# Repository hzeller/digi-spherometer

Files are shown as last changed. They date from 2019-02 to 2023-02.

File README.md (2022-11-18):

A Digital Spherometer
=====================

Converting the sagittal measurement (SAG) from a dial indicator and converting
in your head to a sphere radius is a pain.

This project uses a microcontroller to make this more pleasent: it reads out
the digital indicator and converts the reading to a sphere radius value
printed on an OLED display. It also adds some other nifty features, such as
converting this into the ƒ/N for your mirror size. See [firmware]-page for
feature details.

The microcontroller is an [ATTiny85], the display is a 0.96" [SSD1306], or
1.3" [SH1106] compatible 128x64 OLED display with I²C interface.

Supported dial indicators are [Mitutoyo 543] (good, industry-standard quality)
and a generic [autoutlet-indicator] (relatively cheap, has 1μm resolution but
no documented accuracy figures. Sells under many different names).

The [case](./frame) to hold the dial indicator, microcontroller+display and
batteries is 3D-printed, the base can be laser-cut or machined from some metal
plate.

### Quicklinks

Case | Electronics | Firmware | Calibration
-----|-------------|----------|-------------
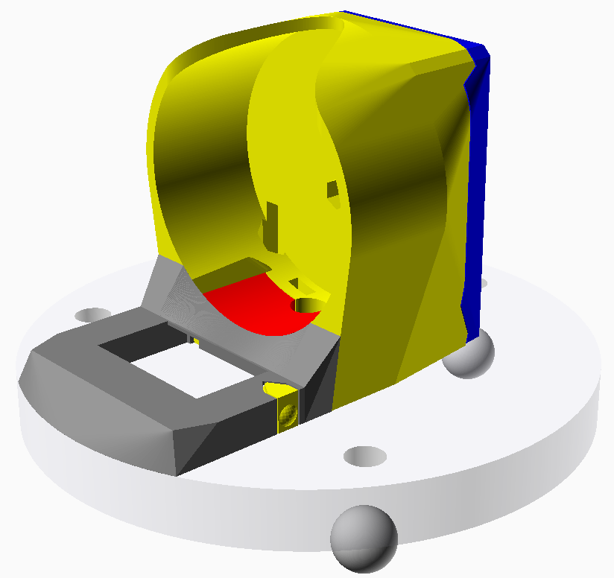
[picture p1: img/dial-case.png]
Case
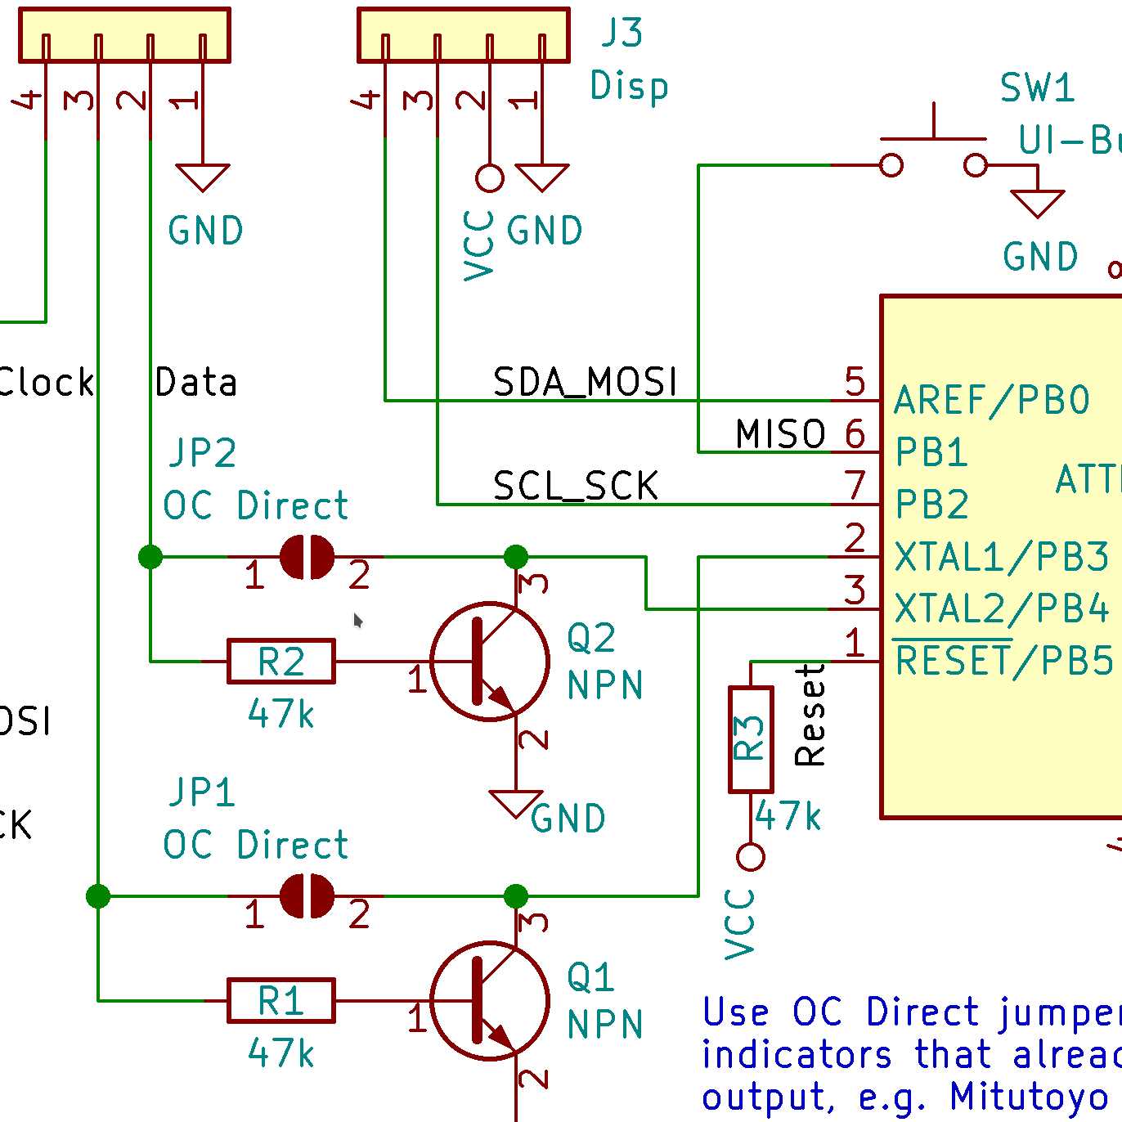
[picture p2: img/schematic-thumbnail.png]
Electronics
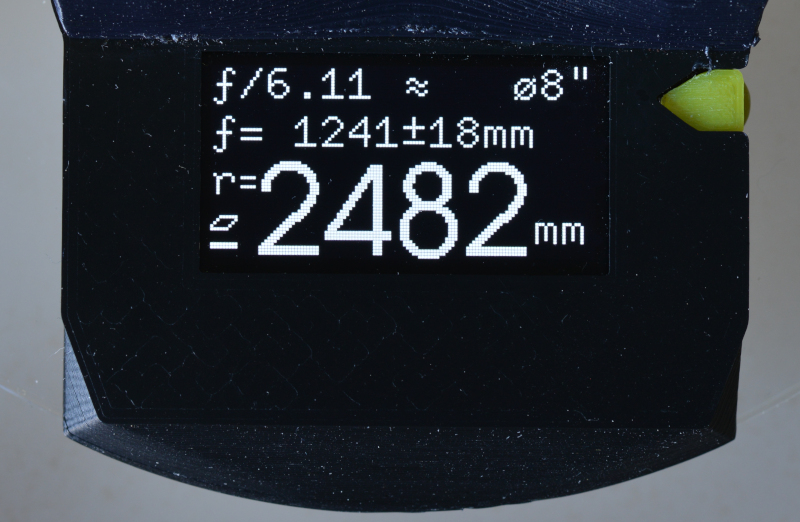
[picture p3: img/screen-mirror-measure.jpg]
Firmware
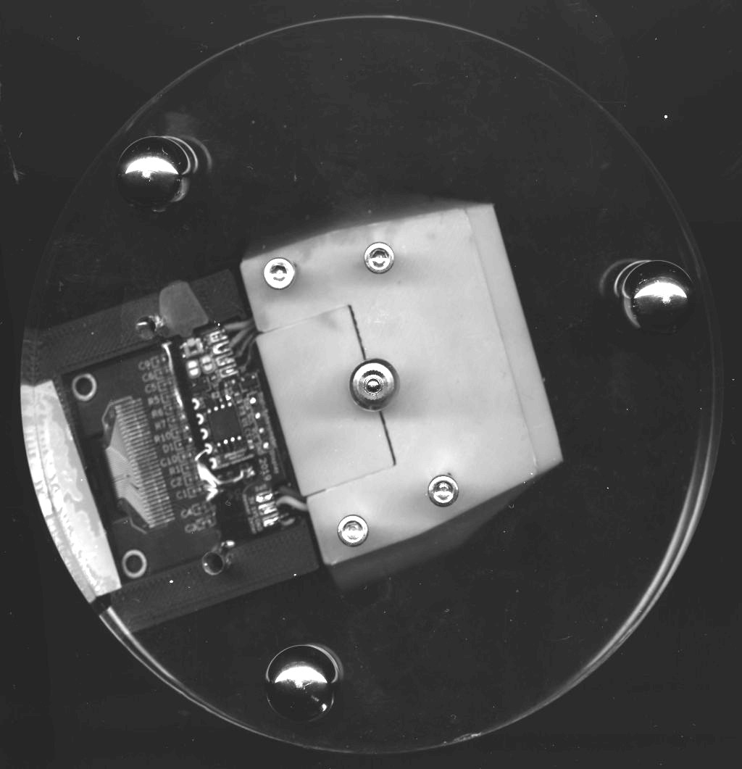
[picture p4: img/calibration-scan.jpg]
Calibration
 |  |  | 

### User Manual

Like any Spherometer, we first need to zero the device on a reference surface.
Typically this is done on a flat surface plate, so this spherometer allows for
that: place it on a flat surface and set the dial indicator to zero.

Unlike other spherometers, this device also allows for another (experimental)
mode: using the grinding tool as a reference surface. The convex shaped tool
has the same (but inverted) curvature as the mirror, so this can be used
as a reference, if the tool and mirror are already sufficiently mated. The
spherometer then can do the math to derive the value from that.

To use that mode, place the spherometer on the tool (make sure the balls and
indicator rest on the tiles not hitting a seam), and zero the dial indicator.
The arrow-shaped button the right side of the display allows to toggle between
the reference mode. The selected mode is highlighted.

Reference on Surface Plate         | Reference on Tool               |
-----------------------------------|---------------------------------|
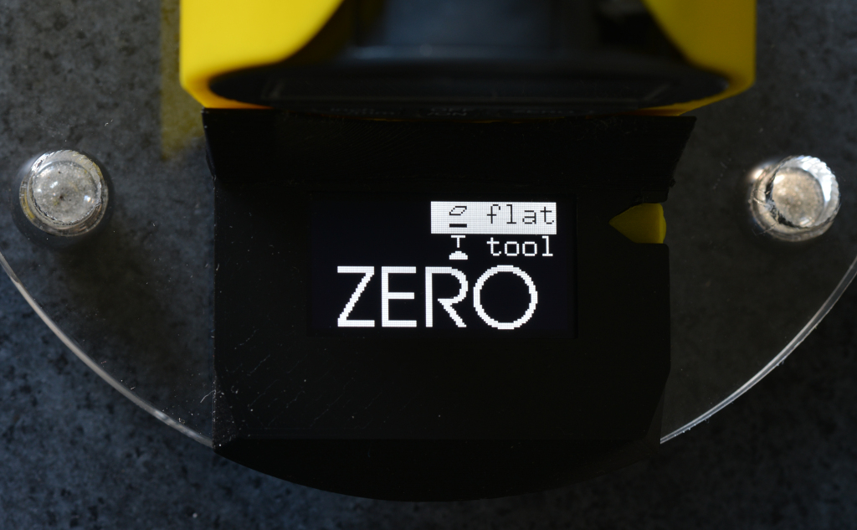
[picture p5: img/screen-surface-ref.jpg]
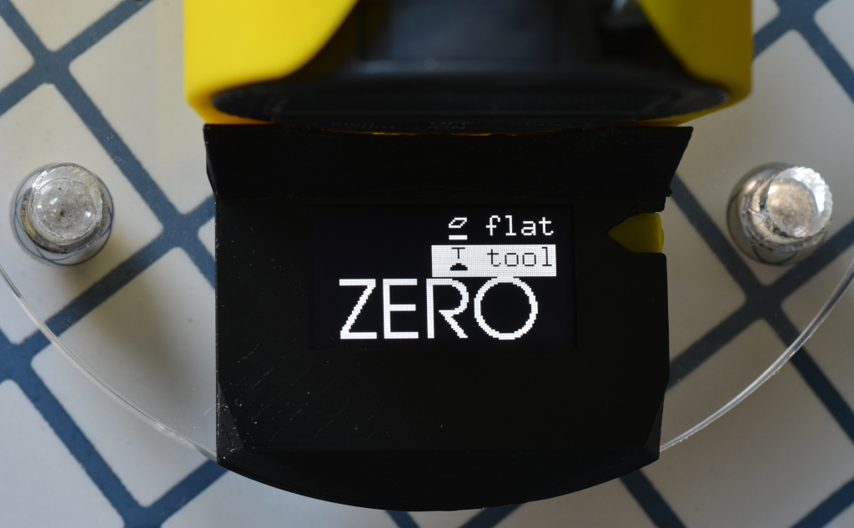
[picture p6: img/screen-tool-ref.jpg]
  | 

The tool reference is probably a bit less accurate, but it does not require
you to be in posession of a flat surface plate.

After the device is zeroed, place it on the mirror. It now shows all relevant
values on one screen. This is what you see from top to bottom:

 * The ƒ/N value for a given mirror size. The mirror size (chosen here: `⌀8"`)
   can be cycled through from a list with the arrow-button.
 * The focal length including error margins derived from dial-indicator error
   and spherometer leg-radius error.
 * The radius is shown in a large font

On the bottom left you see a symbol indicating which reference surface this
was against. There are two symbols indicating flat surface and tool referenced
(same symbols as used in the zero screen).

Millimeter | Inch |
-----------|------|
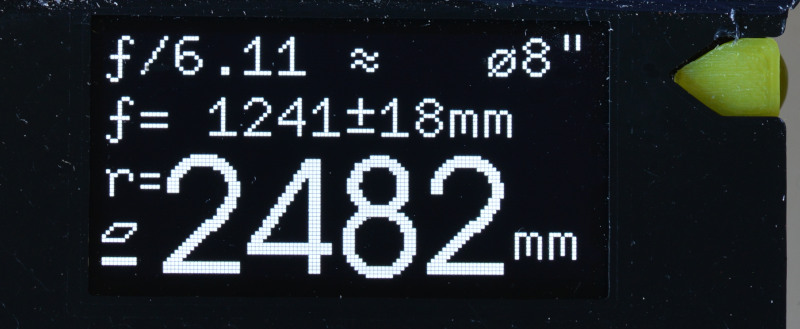
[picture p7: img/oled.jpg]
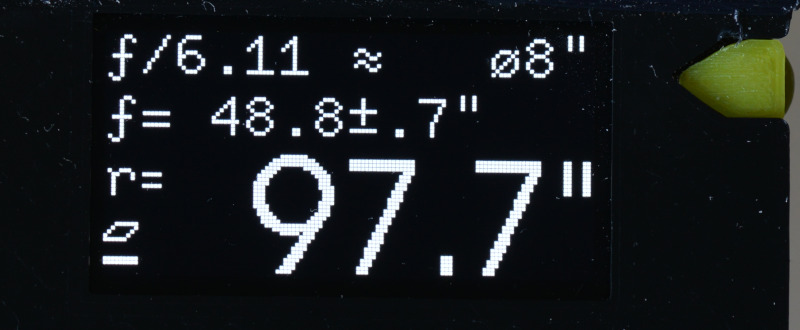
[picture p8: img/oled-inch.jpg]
 | 

So in this example we see in one screen, that this is a mirror with a radius
of about 2482mm, a focal length of 1241mm which is ƒ/6.11 for this
8" mirror. The reference surface was a flat surface plate.

Switching between metric and inch on the dial indicator automatically
switches the calculated values to the corresponding units.

The device does not need an additional power button: it auto-detects
when the drop-indicator is switched off and goes to sleep.

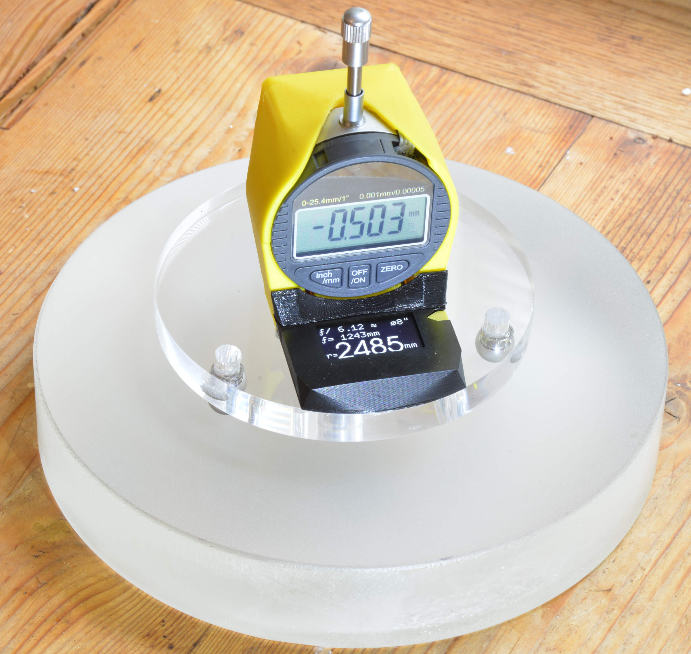
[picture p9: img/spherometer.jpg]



[attiny85]: https://www.microchip.com/wwwproducts/en/ATtiny85
[ssd1306]: https://www.ebay.com/sch/i.html?_nkw=ssd1306+i2c+128x64
[sh1106]: https://www.ebay.com/sch/i.html?_nkw=sh1106+i2c+128x64
[Mitutoyo 543]: https://www.mitutoyo.com/products/small-tool-instruments-and-data-management/indicators/digimatic-indicators/absolute-digimatic-indicator-id-s/
[autoutlet-indicator]: https://www.amazon.com/gp/product/B07C63VFN3
[avr-gcc]: https://gcc.gnu.org/wiki/avr-gcc
[firmware]: ./firmware/README.md

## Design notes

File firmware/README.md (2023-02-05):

Firmware Digi-Spherometer
=========================

The Firmware runs on an [ATTiny85]. The digital drop meter is connected to two
IO-pins, the [SSD1306 screen]/[SH1106 screen] is controlled via I²C.

See the [electronic](../pcb) section about the wiring.

### Install
To build, install the `avr-gcc` toolchain and `avrdude`. There is no
boot-loader, we directly program the chip with an AVR-compatible programmer
through the SPI in-circuit programming pins of the ATTiny85.

The first time the chip is programmed, make sure to set the fuses:
```bash
make fuse
```

Then, compiling and pushing new code to the ATTiny is as simple as invoking
`make flash`. There are some defines that you can pass directly on the
command-line, see [Makefile](./Makefile). In particular after
[calibration](../calibration), you might want to define the exact measured
spherometer radius.

```bash
make USER_DEFINES="-DSPHEROMETER_RADIUS_MM=50.2 -DALLOW_CONVEX_MEASUREMENTS=1" flash
```

The default compile works with the Autoutlet dial indicator. If you use a
Mitutoyo indicator, add `-DINDICATOR_MITUTOYO` to your `USER_DEFINES`.

These are the configuration options, settable via defines in the make commandline:

define                   | default value | Description
------------------------ |---------------|------------------------------------
DISP_SSD1306             | undefined     | Define if SSD1306 instead of SH1106 display is used
DISPLAY_I2C              | 0x78          | I²C address of display.
INDICATOR_DECIMALS       | 3             | Millimeter decimals supported. 3 means: resolution 1μm
INDICATOR_MITUTOYO       | undefined     | Read Mitutoyo instead of Autolet indicator
SPHEROMETER_RADIUS_MM    | 50.000        | Radius of spherometer ring, distance of balls to center.
SPHEROMETER_RADIUS_ERROR_MM | 0.1        | Accuracy of the spherometer radius. Influences error calculation
SPHEROMETER_FEET_BALL_DIAMETER_MM | 12.7 | Diameter of 'feet'-balls used for the ball correction.
TOOL_REFERENCE_FEATURE | undefined | If set to 1: Provide tool reference feature.
ALLOW_CONVEX_MEASUREMENTS| undefined     | If set to 1: Allow to measure also convex surfaces (shows radius negative and applies appropriate ball correction).
SCREENSAVER_SAMPLE_COUNT | undefined     | A number. If defined, turn off display after this number of samples with no change in measurement (good value would be around 1000). Use this for indicators such as Mitotoyo that don't auto-power off somewhat quickly. Reduces current consumption from ~15mA to ~4mA.

#### Mirror size choices for ƒ/N calculation
If you want to change the list of apertures to choose from for the
ƒ/N calculation (currently 6", 8", 10", 12" and 16") look for `aperture_items`
in `main.cc`.

### Interesting nitbits

#### Display and Font Handling
The ATTiny85 RAM is small (512 Byte), which does not allow for having a
frame-buffer for the 128x64 display (1KiB) in memory as many implementations do.
The fonts are compiled-in and directly copied from `PROGMEM`-memory.

The I²C and OLED display code is freshly implemented with only the relevant
features. The display-code only uses features from the SH1106 controller, so it
is compatible with SH1106 and SSD1306 (you still need a compile-time option
to distinguish the displays as there is a different pixel-offset).

The fonts were [generated as compact C-Arrays][bdfont.data] from bitmap BDF
fonts so that they can be compiled into the binary.

Fonts can be 'sparse' and only contain characters really needed in the
application. Also the encoding of each glyph is chosen to be optimal from a
choice of various run-length-encodings. This is necessary as flash-memory in
the ATTiny is pretty limited with 8KiB but we also use a fairly large font.
The [bdfont.data] project provides [Plane 0] UTF8 support, which makes
it easy to include special characters such as `ƒ`, `μ` or` ⚠`;
it is a separate project, check it out if you need font-support in your small
devices.

#### Error propagation
The error margins are done by having a (very simplistic) implementation of
a number data type and operators that do error propagation. That makes
the code very readable as the formula is written as if they were normal
numbers. But the whole chain of calculations are based on this `ErrorFloat`
type: the source of information, the diameter definition of the spherometer
and the values read from the dial indicator include the error margins, which
are then propagated through the spherometer calculation.

All calculations are all done with the `float` datatype;
even though this means somewhat larger code (as the ATTiny does not have a
floating point unit), it makes the code very readable.
Also: fixed point arithmetic would likely be somewhat complicated as we have
to deal with many order of magnitude range (squaring very large and very small
numbers).

#### Sleep
The device does not need an additional power button: it auto-detects
when the drop-indicator is switched off (because it stops sending updates), and
then goes to deep sleep; In that mode, the ATTiny only consumes < 0.8μA current
(plus some current drawn from the display in sleep mode).

The spherometer wakes up by registering a level interrupt on the indicator
clock line: as soon as it sees activity there, it comes out of sleep and
shows the relevant values.

#### Testing
After building with all the configurable parameters, there is also a program
called `host-testing` available, with all these parameters built-in for
testing on the local machine. This allows checking results without first
flashing to the microcontroller.

It takes any number of measurement values on the command line and outputs
the calculated:

```bash
./host-testing 0.7mm -0.5mm 0.02in
== Spherometer constants ==
Ball radius       :    6.350mm
Leg radius        :   50.000mm (-0.100mm/+0.100mm)
Assumed Dial error:    0.003mm
Assuming concave mirrors result in negative value readings.

== Measurements ==
    0.700mm (-0.003mm/+0.003mm)  => 1779.714mm (-14.73mm/+14.87mm) convex radius
-   0.500mm (-0.003mm/+0.003mm)  => 2506.600mm (-24.84mm/+25.16mm) concave radius
    0.020in (-0.0001in/+0.0001in)  =>   96.635in (-0.954in/+0.966in) convex radius
```

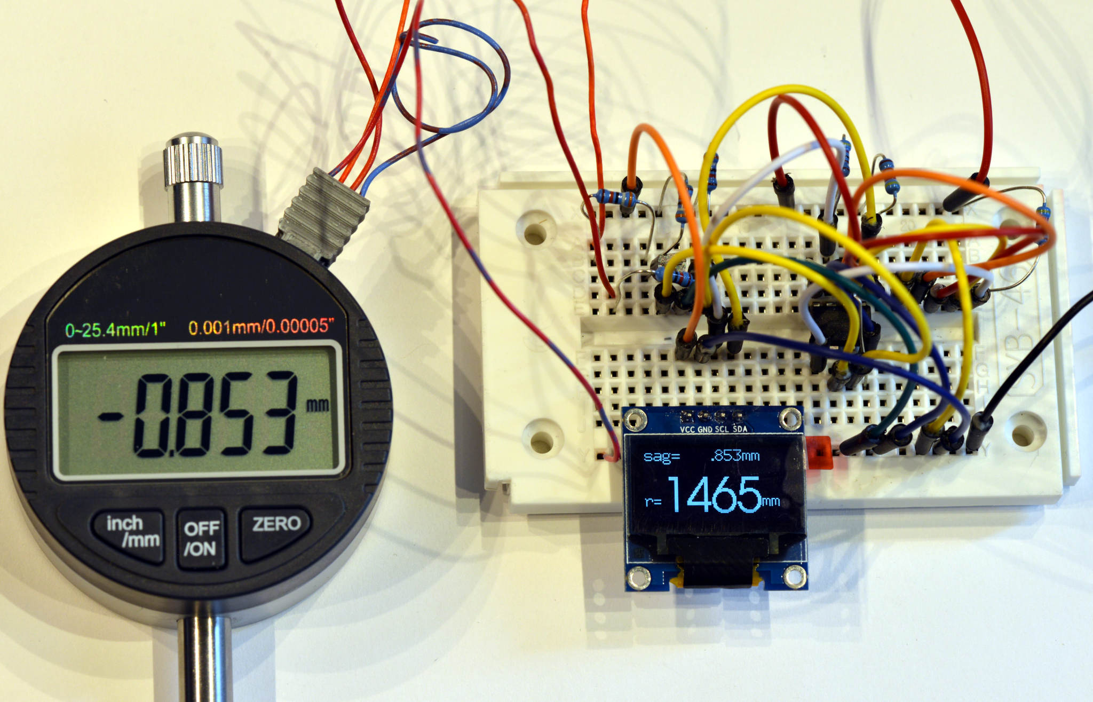
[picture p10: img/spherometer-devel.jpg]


[attiny85]: https://www.microchip.com/wwwproducts/en/ATtiny85
[ssd1306 screen]: https://www.ebay.com/sch/i.html?_nkw=ssd1306+i2c+128x64
[sh1106 screen]: https://www.ebay.com/sch/i.html?_nkw=sh1106+i2c+128x64
[Plane 0]: https://en.wikipedia.org/wiki/Plane_(Unicode)#Basic_Multilingual_Plane
[bdfont.data]: https://github.com/hzeller/bdfont.data

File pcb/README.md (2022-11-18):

Electronics
===========

Schematic is pretty straightforward, mostly things are wired up directly
to the Attiny85. Level conversion of the 1.5V signals from the indicator is
done with some generic NPN transistors.

Some dial indicators, such as Mitutoyo, already have an open collector output,
in that case, the jumpers allow to directly connect the device. The
`R1`, `R2`, `Q1`, `Q2` components need not be populated in that case.

There are two slot connectors on the board, on one side to connect the indicator
(GND, CLK and DATA and optional 1.5V), the other to connect the battery. The
placement is in accordance with the 3D-printed cases.
The connectors are slots to allow for a convenient, low-profile soldering of
wires to it (wires vanish completely inside the slots).
At the top there is some space for easier wire-management (see picture below).

Some indicators (such as the autoutlet) can be powered from an external 1.5V
source; if the battery-pack is tapped in the middle, this is passed through.
Do not use at this point, leave the 1.5V slots disconnected: turns out that the
long battery wire and the connection to the μC injects too much noise. Might
need some filtering.

The board is designed with cut-outs to stay clear of components on the
particular display module I was using to place the board with no gap on the
module; YMMV.

### BOM

Count  | Part                     | Footprint          | Designators  | Remarks
-------|--------------------------|--------------------|--------------|---------
1      | Attiny85V-10             | SOIC-8 5.3mm wide  | U1           |
1      | Capacitor 100n           | 0603 (1608 Metric) | C1           |
3      | Resistor 47k             | 0603 (1608 Metric) | R1, R2, R3   |
2      | MMBTA06LT1HTSA1          | SOT23              | Q1, Q2       | Any SOT23 NPN will do
1      | Panasonic EVQ-P7L01P     | (custom)           | SW1          |
1      | SH1106 Display (i2c)     | (custom)           | Disp         |

Then of course a 1.3" SH1106 module with I²C interface. Make sure the pins
come in sequence `SDA`, `SCL`, `VCC`, `GND` if looked from the back.

### Schematic
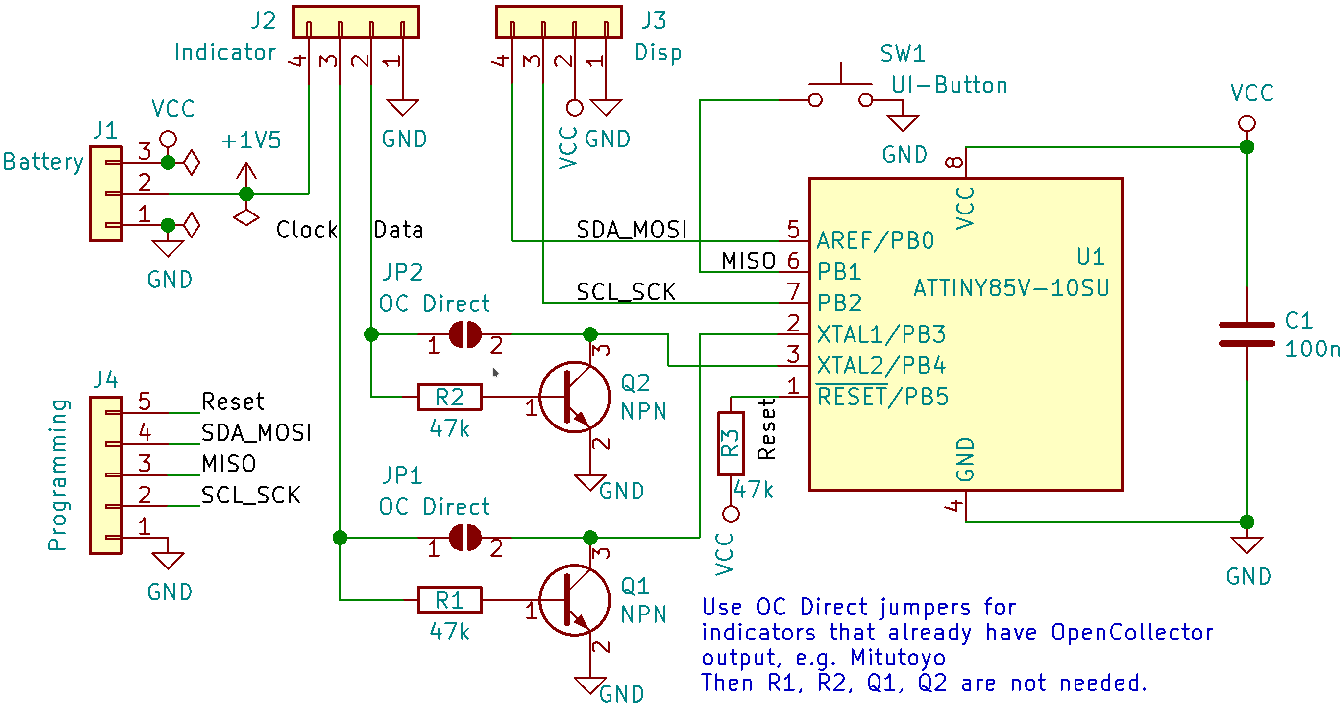
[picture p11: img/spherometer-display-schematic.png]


### PCB
This board is soldered to the back of a 1.3" OLED display

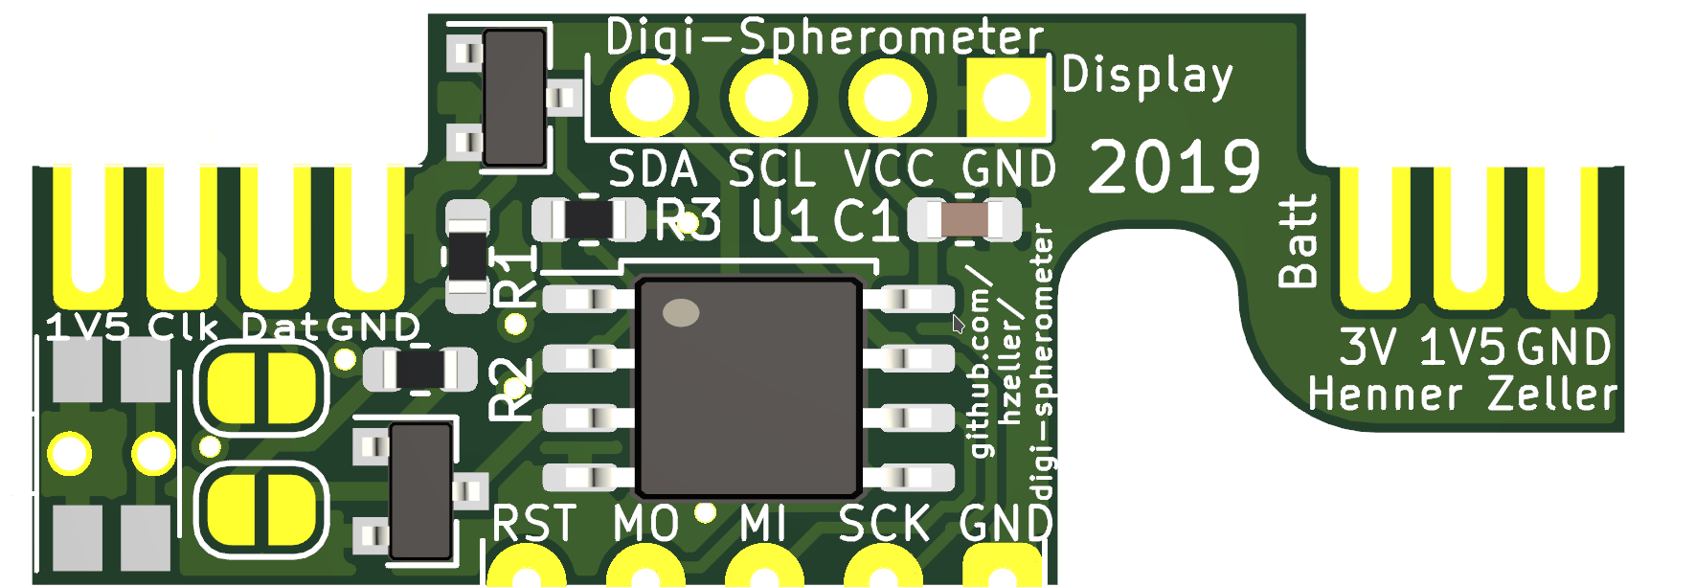
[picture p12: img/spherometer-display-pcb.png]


Also [shared here on OshPark](https://oshpark.com/projects/MvLMlrob); to keep
things thin, order with 0.8mm thickness.

### View through acrylic bottom
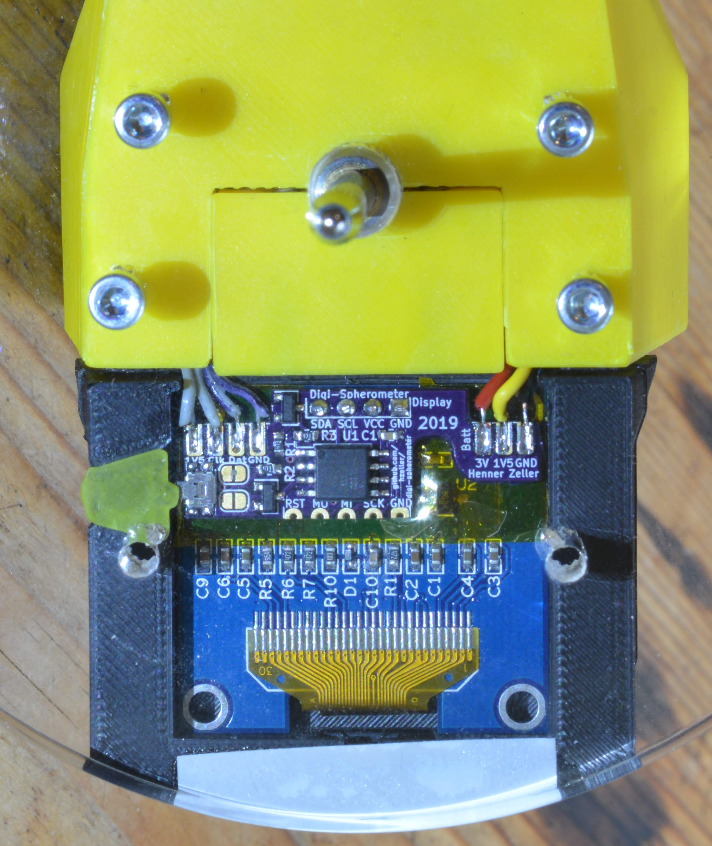
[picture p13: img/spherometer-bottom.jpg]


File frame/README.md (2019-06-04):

Case for the Spherometer
========================

These are generated with OpenSCAD.

To generate, OpenSCAD needs to be installed, then just run

```
make -j6
```

which produces all the relevant fabrication files in the `fab/` sub-directory

```
make
$ ls fab/
display_case_button.stl
display_front_part.stl
display_transition_part.stl
leg_plate_2d.dxf
spherometer_frame_battery_lid.stl
spherometer_frame_main_block.stl
spherometer_frame_stem_squeeze_block.stl
```

All 3D printed parts are emitted as STL, the shape of the base-plate as DXF.

Cut the base-plate, e.g. using a laser cutter from acrylic (I used 12mm thick
one), or use it as guidance to machine a base-plate from metal.

Place the STL parts flat on your build-plate using the features of your slicer.
The main-block best prints upright, you might only need a little support on
the overhanging arch on top when printing with ABS (PLA might be fine).
The overhang inside the battery box is fine without support, even with ABS.
Use specific supports, not autogenerated supports as they tend to clog-up the
screw-holes.

Display case is best printed upside down to have a nice flat front-surface. The
display transition part is separate and can be glued to it later.

All screws are M3.


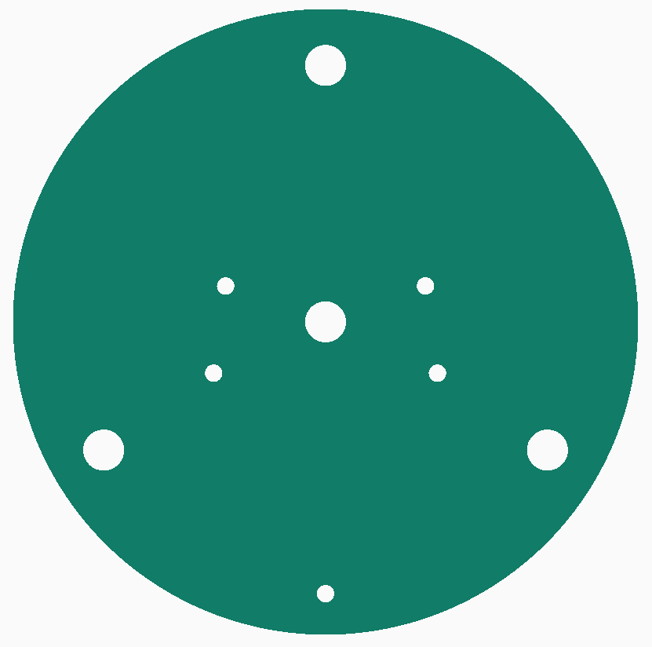
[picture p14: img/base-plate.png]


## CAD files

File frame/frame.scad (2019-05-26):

// -*- mode: scad; c-basic-offset: 2; indent-tabs-mode: nil; -*-
// Mounting frame holding the indicator and display
// CAVE: Super-hacky right now while exploring different shape ideas.
// Now that it is more clean: need some clean-up.
//
// Rough nomenclature:
// Something called 'punch' is a negative space.
//
// Parts often come in two modules: foo() and foo_punch(). foo() defines the
// outer size, while foo_punch() the negative space. They are separate as often
// negative spaces are applied after part is built up (e.g. you want to have
// screw holes punch through all assembled parts).
//
// Some parts also come with a foo_separator(). This defines some cut through
// a part (somtimes with a complicated shape), which can separate a larger
// part using a difference() into one half and intersection() to the other half.
// Often fit_tolerance plays a role her as well.


// The following variables are set in the makefile.
print_quality=false;      // print quality: high-res, but slow to render.
version_id="git-hash";    // Identify version for easier re-print
version_date="git-date";  // .. and date of that version.

// Either fast or pretty.
$fs=print_quality ? 0.15 : 1;  // Half the size the printer can do.
$fa=print_quality ? 1 : 6;

e=0.01;             // Epsilon to reliably punch holes
fit_tolerance=0.3;  // Tolerance of parts in contact.

m3_dia=3.4;         // Let it a little loose to not overconstrain things.
m3_head_dia=6;
m3_head_len=3;
m3_nut_dia=5.4 / cos(30) + 2*fit_tolerance;  // div by cos(30) for circumcircle
m3_nut_thick=2.8;

// Sperometer legs.
leg_radius=50;
leg_plate_thick=12.7;    // Thickness of the acrylic used.
leg_ball_dia=12.7;
leg_ball_hole_dia=8;
leg_plate_rim=7;         // Extra acrylic beyond the legs.
leg_plate_radius=leg_radius + leg_ball_hole_dia/2 + leg_plate_rim;

dial_dia=57.5;
dial_cable_thick=1.5;   // Thickness of the data cables.
dial_cable_wide = 6 * dial_cable_thick;  // 4-5 wires + little slack.
dial_wall=dial_cable_thick+1;
dial_thick=25.2;
dial_stem_pos = 21.4-4;  // Position of stem from the frontface
dial_cable_pos=12;   // Position of the cable channel from the front

// Stem of the indicator, the bushing the measuring-rod is moving in.
// Parameters from the autolet indicator.
stem_dia=8;                       // Stem of the meter
stem_bushing_len=21.5;            // How long is the stem bushing
stem_high=stem_bushing_len - leg_plate_thick - dial_wall;
// Mount distance is at least one M3 diameter (2*half an M3), plus some distance
// right and left.
stem_mount_screw_distance=stem_dia + 3 + 2*1.5;

// Battery sizes
aa_dia=14.5 + 2*fit_tolerance;
aa_len=50.5 + 7;  // for contacts
aa_wall=3;
aa_dist = 8;      // Distance between batteries

// Battery box wiggle printing on the back is a challenge. Maybe this needs to
// be split in the wiggle part and flat battery box back, that are then glued
// together.
battery_box_with_wiggle=false;   // Easier to print if false :)
battery_box_rim_deep=1.5;       // Alignment rim all around battery box.

base_dia=dial_stem_pos*2;

display_wall_thick=1.5;
display_top_wall=0.8;    // Front face a little thinner to have display close.
display_wide=52;         // Mostly determined by electronics size and screws.
display_high=36;
display_box_thick=7.5;   // Large enough to house electronics.
display_transition=7;    // Transition blend between dial and display box.
display_front_radius_adjust=-0.5;  // Don't go all the way to the edge of plate
display_button_from_top=10.11;     // Position of the button

// Mounting holes, holding down the back part, the front part and the
// display part.

// The Squeeze-block is the block squeezing in the stem.
squeeze_block_mount = false;  // Should we have an extra mount hole for sq-block
squeeze_block_wide = 2 * stem_mount_screw_distance;

cable_channel_from_bottom = 2.5;    // Cable slot access from the bottom.
cable_channel_distance=squeeze_block_wide / 2;
cable_channel_front_wide=3;

front_width=squeeze_block_wide + 2*cable_channel_front_wide + 2*m3_nut_dia + 4;
// TODO: Naming of these is confusing.
bottom_mount_front_offset=10;  // Bottom screws. Offset from center to back.
bottom_mount_center_offset=bottom_mount_front_offset + 0;
bottom_mount_front_distance=front_width - 8;  // right/left distance.

// Center screw in display-front.
bottom_mount_front_display_center_offset=leg_plate_radius - 8;

bottom_mount_back_offset=7;  // Bottom screws. Offset from center to back.
bottom_mount_back_distance=display_wide - 13;  // right/left distance.

function max(a, b) = a > b ? a : b;

// m3_screw space occupied by a M3 screw with optional nut and
// nut-access channel. Screw is centered around the Z-axis, with the
// screw in the positive and screw-head in the negative range.
// nut_at: start of where a m3 nut shoud be placed. -1 for off.
// nut_channel: make a channel of given length to slide a nut in.
//              nut channel extends in negative Y direction. Rotate as needed.
module m3_screw(len=60, nut_at=-1, nut_channel=-1, nut_thick=m3_nut_thick) {
  cylinder(r=m3_dia/2, h=len);
  translate([0, 0, -20+e]) cylinder(r=m3_head_dia/2, h=20);
  if (nut_at >= 0) {
    translate([0, 0, nut_at]) {
      rotate([0, 0, 30]) cylinder(r=m3_nut_dia/2, h=nut_thick, $fn=6);
      nut_wide=m3_nut_dia * cos(30);
      if (nut_channel > 0) {
        nut_channel_len = max(nut_channel, m3_nut_dia/2);
        translate([-nut_wide/2, -nut_channel_len, 0]) cube([nut_wide, nut_channel_len, nut_thick]);
      }
    }
  }
}

// A block that looks like a cut through a cosine curve. Size parameter
// similar to cube(), but x/y direction is symmetric to center, so the
// actual width/height is twice. (TODO: make more like cube)
module cos_block(a=[10,10,10]) {
  p = [ for (x = [-180:1:180]) [ x/180, cos(x)/2] ];
  linear_extrude(height=a[2]) scale(a) polygon(p);
}

// Make a 2D shape of length in X direction of "len", height in y-direction
// of "Y" that has "wiggle_count" bumps.
module sine_wiggle(wiggle_count=3, len=20, height=2, resolution=0.01) {
  points = [ for (w = [0 : resolution : 1.0]) [ w * len, height/2 + height/2 * sin(w*wiggle_count*360-90)] ];
  points1=concat([[0, -e]], points, [[len, -e]]);
  translate([-len/2, 0, 0]) polygon(points1);
}

// A corner for a champfered box, represented as tiny objects for which it
// is simple to wrap a hul() around.
// this is for a front-left corner. Origin is at the bottom end of the corner,
// the x and y direction size allow for different champfer angles in x and y
// direction.
// To use in different corners, it is probably easiest to mirror it (
// using scale around the origin).
module champfer_point_cloud(height=display_box_thick, side_x=3, side_y=8) {
  a=e;
  f=0;  // front champfer
  cube([a, a, a]);
  translate([0, side_y, height]) cube([a, a, a]);
  translate([side_x, f, height]) cube([a, a, a]);
  translate([side_x, 0, height-f]) cube([a, a, a]);
}

// Stem of indicator.
module stem_punch() {
  // A little thinner in y direction to have enough 'squeeze' action.
  scale([1, 0.98, 1]) translate([0, 0, -25]) cylinder(r=stem_dia/2, h=50);
}

// Base where everything is sitting on the bottom.
module base(with_front_flat=true) {
  scale([1, 1, 1]) cylinder(r=base_dia/2, h=0.8);
  translate([-front_width/2, -base_dia/2, 0]) cube([front_width, base_dia/2, 2]);
  if (with_front_flat) {
    translate([-front_width/2, -base_dia/2, 0]) cube([front_width, 1, stem_high]);
  }
}

// Some text helping to identify from which git-hash this has been printed for
// easier re-print.
module version_punch(thick=1) {
  fs=5;
  color("red") linear_extrude(height=thick) {
    text("© H. Zeller", halign="center", size=fs);
    translate([0, -1*(fs+1)]) text(version_date, halign="center", size=fs);
    translate([0, -2*(fs+1)]) text(version_id, halign="center", size=fs);
  }
}

// Outer case to hold the dial.
module dial_holder() {
  wall_r =dial_dia/2 + dial_wall;
  rotate([90, 0, 0]) translate([0, wall_r+stem_high, -dial_thick+dial_stem_pos]) cylinder(r=wall_r, h=dial_thick);
}

module dial_holder_cable_punch() {
  connector_from_top=13;
  wall_r = dial_dia/2 + dial_wall;
  connector_angle_from_top=90
    + 360 * (-dial_cable_wide - connector_from_top) / (dial_dia * PI);
  connector_angle_width=360 * dial_cable_wide / (dial_dia * PI);
  hull() {
    bottom_wide=dial_cable_wide;
    back_channel_depth=1.2*dial_cable_thick;
    // Front channel access
    translate([cable_channel_distance, -dial_stem_pos-e, cable_channel_from_bottom]) cube([cable_channel_front_wide, 1, stem_high+10]);

    // Bottom back channel
    translate([cable_channel_distance-bottom_wide/2, dial_thick-dial_stem_pos, dial_wall+7]) cube([bottom_wide, back_channel_depth, dial_cable_thick]);
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

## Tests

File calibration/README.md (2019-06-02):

Calibration
==========

Any mechanical system build to dimensions will be slightly off from the desired
dimensions.  These inaccuracies might be small (if a CNC machine was used) or
larger if built by hand. If we measure the final outcome, we can correct for
that as we can feed back the measured dimensions into the firmware.

The dimension that is critical for correct measurements it the distance
of the dial indicator tip to the edge of the circle spanned by the three
balls on the base-plate. Note: in many articles about spherometer
calibration, you only see calculations of the radius of circle spanned
by the legs. But given that the indicator stem might be off-center, the really
interesting value is the _closest_ distance from that stem to the leg-circle.

Once we have measured that radius, we can update the firmware using the radius
we measure.

Let's discuss three options.

# 1. Simple measurement

In the simplest case, we just measure the distance between the ball and the
stem of the indicator. We measure from the outside of the ball to the opposing
side of the stem. We get the radius by substracting the radius of the balls
(here: diameter 12.7mm) and the radius of the stem (here: diameter 4.5mm),
that we measure separately. So the radius in this example is
**58.24mm - 12.7mm/2 - 4.5mm/2 = 49.64mm**

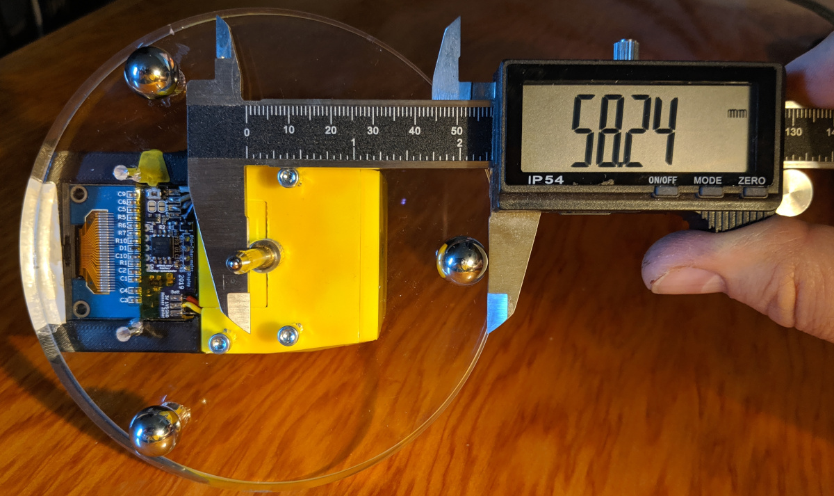
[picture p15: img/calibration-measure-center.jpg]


We do this for all legs and simply use the smallest value. This is only an
approximation as the off-center direction might not be in-line with one
of the measurements, but probably fairly accurate.

# 2. Comprehensive measurement

Here, we would measure the distance between each ball and calculate the radius
of the equivalent circle. Then we measure the distance from each ball to the
center. From there, we can work out exactly the relative position of the stem
to the legs and determine the closest position of the stem to the edge of the
leg-circle. Math left as an exercise for the reader.

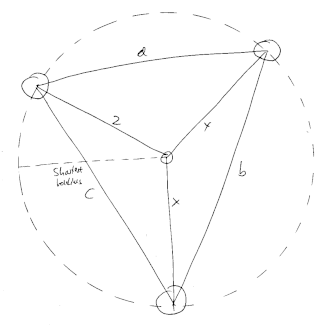
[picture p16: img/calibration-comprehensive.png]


# 3. Optical measurement

For this different kind of comprehensive measurement, we'll use an optical
tool: a flatbed scanner. It has a pretty accurate fixed pixel-to-realworld
size translation which allows us to determine accurate absolute measurements.
This can give us in the order of 1/100mm accurate measurements ... if the
points to measure provide a high-contrast point, which is unfortunately not
true with the steel balls.

## Scanning

Put your final spherometer on the bed and create a high-resolution scan
(>= 600dpi). Be aware that the resulting images are _very_ large, so make sure
to select only the relevant part in the preview.



It might be a little hard later to find the exact center where the ball hits
the surface. Maybe experimenting putting the balls in a little puddle of ink
might be a good idea. In my case, the center of the balls were ever so slightly
scratched where they were touching a surface bfore, so it was fairly simple
to see the center.

## Measuring

Load the image into your favorite image editing program (I use [gimp]), and
zoom into the relevant parts and hover the mouse-cursor right where you see
the center of the ball. Write down the coordinate where that is (in gimp, it
shows in the status line at the bottom).

Do this for all three balls, then the center and write these coordinates
to a file. These coordinates can be quite large numbers as the scan has a
pretty high resolution.

All coordinates are written to a text-file; here are the are numbers for my
spherometer scanned with 2400dpi, written to a textfile `positions.txt`.

```
6385  9605
14629 9845
10731 2616
10590 7313
```

## Calculating scan results

Now, we want to convert these values to something useful to plug into our
firmware.

For that, there is a little program in this directory you can use. Build it:

```
make
```

Now, we can use the resulting `spscan` program. We just give it the coordinates
from above on stdin, and also tell the program that the resolution was in
2400dpi:

```
./spscan 2400 < positions.txt
Circle radius...............: 50.289mm
Indicator to true center....:  0.573mm
Effective Spherometer radius: 49.716mm
```

Done. Maybe you want to re-do the measurements a couple of times with different
rotations on the scanner to even out slight aspect-ratio and reading issues.
Take an average of that effective spherometer radius measurement.

# Firmware update

Using one of the methods above, we now have a radius that is closer to reality.
Now we can build the firmware with the calculated value for more accurate
readings:

```
cd ../firmware
make USER_DEFINES=-DSPHEROMETER_RADIUS_MM=49.906
```

See the [firmware-page](../firmware) for building and flashing instructions.

[gimp]: https://www.gimp.org/

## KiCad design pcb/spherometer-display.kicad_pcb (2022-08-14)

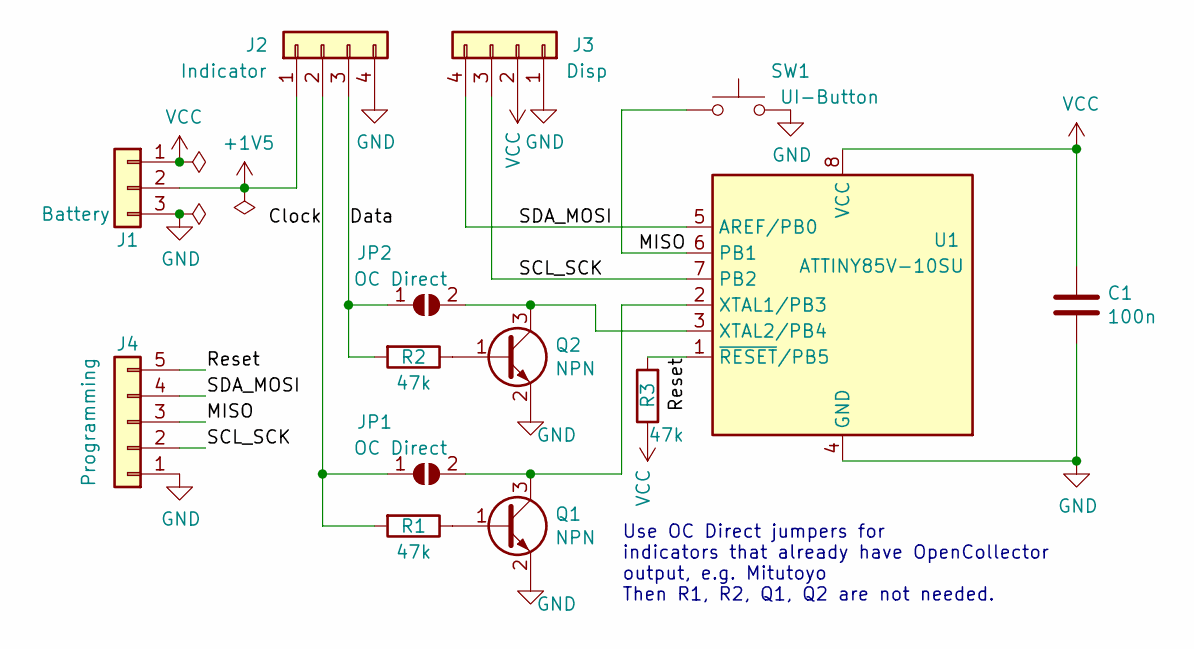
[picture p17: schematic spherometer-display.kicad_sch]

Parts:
C1: 100n; C_0603_1608Metric
J1: Battery; connect-edge-3slot-2mm
J2: Indicator; connect-edge-4slot-2mm
J3: Disp; PinHeader_1x04_P2.54mm_Vertical
J4: Programming; PinHeader_1x05_P2.54mm_Vertical
JP1, JP2: OC Direct; SolderJumper-2_P1.3mm_Open_RoundedPad1.0x1.5mm
Q1, Q2: NPN; SOT-23
R1, R2, R3: 47k; R_0603_1608Metric
SW1: UI-Button; EVQP7-Switch
U1: ATTINY85V-10SU; SOIC-8_5.23x5.23mm_P1.27mm

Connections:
+1V5: J1.2, J2.1
/Clock: J2.2, JP1.1 (A), R1.2
/Data: J2.3, JP2.1 (A), R2.2
/MISO: J4.3, SW1.2, U1.6 (PB1)
/Reset: J4.5, R3.2, U1.1 (~RESET/PB5)
/SCL_SCK: J3.3, J4.2, U1.7 (PB2)
/SDA_MOSI: J3.4, J4.4, U1.5 (AREF/PB0)
GND: C1.2, J1.3, J2.4, J3.1, J4.1, Q1.2 (E), Q2.2 (E), SW1.1, U1.4 (GND)
unnamed: JP1.2 (B), Q1.3 (C), U1.2 (XTAL1/PB3)
unnamed: JP2.2 (B), Q2.3 (C), U1.3 (XTAL2/PB4)
unnamed: Q1.1 (B), R1.1
unnamed: Q2.1 (B), R2.1
VCC: C1.1, J1.1, J3.2, R3.1, U1.8 (VCC)

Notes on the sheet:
Use OC Direct jumpers for indicators that already have OpenCollector output, e.g. Mitutoyo Then R1, R2, Q1, Q2 are not needed.

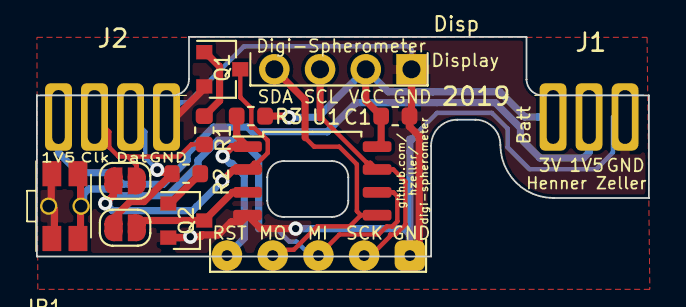
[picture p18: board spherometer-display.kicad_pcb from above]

Board: 2 copper layers, 34.0 x 12.2 mm, 14 parts (0 on the bottom side), 13 nets.

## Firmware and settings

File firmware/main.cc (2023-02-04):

// -*- mode: c++; c-basic-offset: 2; indent-tabs-mode: nil; -*-
//
// Copyright (C) 2019 Henner Zeller <h.zeller@acm.org>
//
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
#include <avr/interrupt.h>
#include <avr/io.h>
#include <avr/pgmspace.h>
#include <avr/power.h>
#include <avr/sleep.h>
#include <avr/sleep.h>
#include <math.h>
#include <stdint.h>
#include <util/delay.h>

#include "sh1106-display.h"
#include "strfmt.h"
#include "error-float.h"
#include "i2c-master.h"

// Compiled-in fonts we're using for the UI.
#include "font-bignumber.h"
#include "font-smalltext.h"
#include "font-tinytext.h"

#include "dial-data.h"
#include "spherometer-calculation.h"

// ------------------------------ configurable parameters ------------
/*
 * Choices of mirror diameters to be cylced through. In every workshop, there
 * are typically only a few common mirror sizes to deal with, so a single
 * button allows to cycle through them.
 * There is a display text which can show any text or unit, while the actual
 * value is stored in millimeter for the calculation.
 *
 * All texts should have the same width.
 */
static constexpr int kApertureChoices = 5;
static constexpr struct {
  const char *text;
  const float mm;
} aperture_items[kApertureChoices] = {
  { "   ⌀6\"",  6*25.4 },
  { "   ⌀8\"",  8*25.4 },
  { "  ⌀10\"", 10*25.4 },
  { "  ⌀12\"", 12*25.4 },
  { "  ⌀16\"", 16*25.4 },
};

static constexpr uint8_t BUTTON_BIT = (1<<1);  // A button as UI input.

// Pins the dial indicator is connected to.
static constexpr uint8_t CLK_BIT  = (1<<3);
static constexpr uint8_t DATA_BIT = (1<<4);

// Read dial indicator and set "data" to new value.
//
// The dial indicator header needs to provide this function reading from
// the CLK_BIT and DATA_BIT to read from PINB.
//
// Return 'true' if successful, 'false' if indicator is not sending
// data (i.e. is switched off).
static inline bool ReadDialIndicator(uint8_t clk_bit, uint8_t data_bit,
                                     DialData *data);

// Choose dial indicator implementation here.
#ifdef INDICATOR_MITUTOYO
#  include "dial-indicator-mitutoyo.h"
#else
#  include "dial-indicator-autoutlet.h"
#endif


// Get microcontroller to deep sleep. We enable a level changing interrupt
// to come back online. We are listening on the clock line of the dial
// indicator for that. That way, we don't need any own power button.
EMPTY_INTERRUPT(PCINT0_vect);
static void SleepTillDialIndicatorClocksAgain() {
  // TODO: make this work for Atmega and choose level change interrupt there
  cli();
  GIMSK |= (1<<PCIE);   // level change interrupt
  PCMSK = CLK_BIT;      // Switch on level detection on the CLK of indicator
  set_sleep_mode(SLEEP_MODE_PWR_DOWN);

  sleep_enable();
  sei();
  sleep_cpu();

  // Zzzz...

  // Waking up due to interrupt.
  sleep_disable();
  GIMSK = 0;
}

// Keep track of button release before next clicked() event is triggered.
class Button {
public:
  Button() { PORTB |= BUTTON_BIT; /* pullup */}

  // While at sleep, we don't want button presses to use power. Also, this
  // is a nice way to measure from the outside if we are in sleep mode.
  void SleepMode(bool s) {
    if (s) {
      PORTB &= ~BUTTON_BIT;
    } else {
      PORTB |= BUTTON_BIT;
    }
  }
  bool clicked() {
    const bool current_press = (PINB & BUTTON_BIT) == 0;  // negative logic
    const bool before = previous_pressed_;
    previous_pressed_ = current_press;
    return (current_press && !before);
  }

private:
  bool previous_pressed_ = false;
};

#ifdef SCREENSAVER_SAMPLE_COUNT
class Screensaver {
public:
  bool CheckIsActive(bool measurement_is_same, SH1106Display *disp) {
    /*
     * if we measure the same value for SCREENSAVER_SAMPLE_COUNT times in
     * a row, we switch off the display. This is a useful feature for
     * dial indicators that don't auto-power off.
     * It reduces our current consumption from ~15mA to about ~4mA
     * (Not nearly as down to the 5μA when in deep sleep of course).
     */
    if (measurement_is_same) {
      if (wait_cycles_ < SCREENSAVER_SAMPLE_COUNT) {
        wait_cycles_++;
      } else {
        disp->SetOn(false);
        return true;
      }
    } else {
      if (wait_cycles_) {  // Was possibly screen-saving before.
        disp->SetOn(true);
      }
      wait_cycles_ = 0;
    }
    return false;
  }

private:
  int16_t wait_cycles_ = 0;
};
#else
class Screensaver {
public:
  bool CheckIsActive(bool, SH1106Display *) { return false; }
};
#endif

static void ShowRadiusPage(SH1106Display *disp, DialData dial,
                           uint8_t dia_choice,
                           bool tool_referenced) {
  const ErrorFloat error_radius = spherometer::calc_r(dial, tool_referenced);
  const float radius = error_radius.nominal;
  // Calculating the sag values to radius in their respective units.
  // We round the returned value to an integer, which is the type
  // we can properly string format below.
  // For imperial: fixpoint shift to display 1/10" unit
  const int32_t radius_digits = roundf(dial.is_imperial ? 10 * radius : radius);
  const bool is_overflow = (radius_digits > 9999);   // Limit digits on screen
  const int32_t display_radius = is_overflow ? 9999 : radius_digits;

  uint8_t x;
  // -- Print focal length and ƒ/-Number
  if (is_overflow) {
    // Don't show any numbers in that case. Not very useful.
    for (int y = 0; y < 32; y += 8)
      disp->FillStripeRange(0, 127, y, 0x00);
    disp->Print(font_bignumber, 46, 0, "⚠");
  }
  else {
    const float f = radius / 2;  // Focal length of a sphere.
    const float f_err = (error_radius.high - radius)/2;
    // -- ƒ/-Number according to user choice from button.
    // f/5.43 ≈ ⌀ 6"
    const float f_mm = dial.is_imperial ? 25.4 * f : f;
    const float dia = aperture_items[dia_choice].mm;
    const int32_t f_N = roundf(100 * f_mm / dia);  // 100* for 2 decimal digits
    x = disp->Print(font_smalltext, 0, 0, "ƒ/");
    x = disp->Print(font_smalltext, x, 0, strfmt(f_N, 2));
    x = disp->Print(font_smalltext, x, 0, "  ");
    x = disp->Print(font_smalltext, 64, 0, "≈");
    // Ideally, we'd like to show this inverse to better draw the attention
    // to this number and the arrow-button right next to it.
    // However, it seems to suck brightness out of that line which makes
    // it visually non-pleasing. TODO: Experiment with it once final
    // case with button is there.
    x = disp->Print(font_smalltext, x, 0, aperture_items[dia_choice].text,
                    false);

    // Print focal length in chosen units.
    constexpr int line2 = 16;
    x = disp->Print(font_smalltext, 0, line2, "ƒ=");
    int32_t display_f = roundf(dial.is_imperial ? 10*f : f);
    if (!dial.negative) display_f = -display_f;  // Convex measurements

    x = disp->Print(font_smalltext, x, line2,
                    strfmt(display_f, dial.is_imperial ? 1:0, 5));
    const int32_t display_error_f = roundf(dial.is_imperial ? 10*f_err : f_err);
    x = disp->Print(font_smalltext, x, line2, "±"); // show error as plusminus
    x = disp->Print(font_smalltext, x, line2,
                    strfmt(display_error_f, dial.is_imperial ? 1:0, 0));
    x = disp->Print(font_smalltext, x, line2, dial.is_imperial ? "\"  " : "mm");
    // since we're hugging the ±-value right after the value we show, we need
    // to make sure to clean everything after the value we've written to not
    // leave leftover 'mm' or '"' suffix behind when numbers get shorter.
    // Our text is two stripes high, so let's fill these.
    disp->FillStripeRange(x, 127, line2, 0x00);
    disp->FillStripeRange(x, 127, line2+8, 0x00);
  }

  // -- Printing the radius in a large font.

  // If the value is too large, we don't want to overflow the display.
  // Instead, we clamp it to highest value and show a little > indicator.
  if (is_overflow) {
    disp->Print(font_smalltext, 0, 48, ">");  // 'overflow' indicator
  } else if (!dial.negative) {                // Convex measurements.
    disp->Print(font_bignumber, 0, 32, "-");
  } else {
#if TOOL_REFERENCE_FEATURE
    disp->Print(font_smalltext, 0, 48, tool_referenced ? "⯊" : "▂");
#else
    disp->Print(font_smalltext, 0, 48, " ");
#endif
  }

  // Make sure that it is clear we're talking about the sphere radius
  disp->Print(font_smalltext, 0, 32, "r=");

  // Different formatting of numbers in different units, including suffix
  if (dial.is_imperial) {
    // One decimal point, total of 5 characters (including point) 999.9
    x = disp->Print(font_bignumber, 15, 32, strfmt(display_radius, 1, 5));
    disp->Print(font_bignumber, x, 32, "\"");
  } else {
    // No decimal point, total of 4 characters: 9999
    x = disp->Print(font_bignumber, 15, 32, strfmt(display_radius, 0, 4));
    disp->Print(font_smalltext, x, 48, "mm");
  }
}

// Returns if the absolute measurement value is deemed 'flat'. This should
// be around zero, but indicators can create a little bit of jumping around
// there. Let's be gentle and not drive OCD's crazy having to press the zero
// button all the time.
static inline bool is_flat(int32_t value) { return value < 2; }

int main() {
  PORTB = CLK_BIT | DATA_BIT;  // Pullup for the transistor level converter.
  _delay_ms(500);  // Let display warm up and get ready before the first i2c
  SH1106Display disp;
  Button button;

  DialData last_dial;
  uint8_t last_aperture_choice = 0xff;  // outside range, so guaranteed refresh

  uint8_t indicator_off_waiting_cycles = 0;
  uint8_t aperture_choice = 0;
  Screensaver screensaver;
#if TOOL_REFERENCE_FEATURE
  bool tool_referenced = false;
#else
  constexpr bool tool_referenced = false;
#endif

  constexpr uint8_t kPowerOffAfterCycles = 50;
  constexpr uint8_t kStartShowingOutro = 4;
  DialData dial;
  for (;;) {
    const bool indicator_on = ReadDialIndicator(CLK_BIT, DATA_BIT, &dial);

    // If the dial indicator is off, we watch this for a while. After
    // kPowerOffAfterCycles, we go to deep sleep. In the time between
    // we detect the indicator to be off and going to sleep, we show the
    // github message on the display for people to find the project.
    if (!indicator_on)
      indicator_off_waiting_cycles++;
    else
      indicator_off_waiting_cycles = 0;

    if (indicator_off_waiting_cycles == kStartShowingOutro) {
      disp.ClearScreen();
      last_aperture_choice = 0xff;  // Force refresh of screen after we get out
      disp.Print(font_smalltext, 0, 0, "©Henner Zeller");
      disp.Print(font_tinytext, 0, 16, "github hzeller/");
      disp.Print(font_tinytext, 0, 32, "digi-spherometer");
      disp.Print(font_tinytext, 0, 48, "    GNU GPL");
    }
    else if (indicator_off_waiting_cycles > kPowerOffAfterCycles) {
      disp.SetOn(false);
      button.SleepMode(true);
      I2CMaster::Enable(false);
      SleepTillDialIndicatorClocksAgain();  // ZZzzz...

      // ... We're here after wakeup
      I2CMaster::Enable(true);
      button.SleepMode(false);
      disp.Reset();      // Might've slept a long time. Make sure display ok.
#if TOOL_REFERENCE_FEATURE
      tool_referenced = false;
#endif
      last_dial.raw_count = 0xffffffff;  // Doesn't look like any current sample
    }

    if (indicator_off_waiting_cycles)
      continue;

    if (screensaver.CheckIsActive(dial == last_dial, &disp))
      continue;

    if (last_aperture_choice == 0xff
        || last_dial.negative != dial.negative
        || last_dial.is_imperial != dial.is_imperial
        || is_flat(last_dial.raw_count) != is_flat(dial.raw_count)) {
      disp.ClearScreen();  // Visuals will change. Clean-slatify.
    }

    if (is_flat(dial.raw_count)) {
#if TOOL_REFERENCE_FEATURE
      if (button.clicked()) tool_referenced = !tool_referenced;
      disp.Print(font_smalltext, 60, 0,  " ▂ flat", !tool_referenced);
      disp.Print(font_smalltext, 60, 16, " ⯊ tool", tool_referenced);
#else
      disp.Print(font_smalltext, 48, 0, "flat");
#endif  // TOOL_REFERENCE_FEATURE
      disp.Print(font_bignumber, 12, 32, "ZERO");
    }

#if not ALLOW_CONVEX_MEASUREMENTS
    /*
     * If we are not allowing convex measurements, we use a positive sag
     * value as indication that indicator is not zeroed yet
     */
    else if (!dial.negative) {
      disp.Print(font_bignumber, 46, 0, "⚠");
      disp.Print(font_smalltext, 0, 32, "Please zero on");
#if TOOL_REFERENCE_FEATURE
      disp.Print(font_smalltext, 8, 48, "ref. surface");
#else
      disp.Print(font_smalltext, 8, 48, "flat surface");
#endif  // TOOL_REFERENCE_FEATURE
    }
#endif  // ALLOW_CONVEX_MEASUREMENTS

    // Not in any of the above calibration screens: show regular UI
    else {
      if (button.clicked()) {
        aperture_choice += 1;
        if (aperture_choice >= kApertureChoices) aperture_choice = 0;
      }
      if (dial != last_dial || aperture_choice != last_aperture_choice) {
        ShowRadiusPage(&disp, dial, aperture_choice, tool_referenced);
      }
    }

    last_dial = dial;
    last_aperture_choice = aperture_choice;
  }
}

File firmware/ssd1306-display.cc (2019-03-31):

// -*- mode: c++; c-basic-offset: 2; indent-tabs-mode: nil; -*-
//
// Copyright (C) 2018 Henner Zeller <h.zeller@acm.org>
//
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
#include "ssd1306-display.h"

#include <avr/pgmspace.h>
#include <stdlib.h>

#include "utf8-iterator.h"

static constexpr uint8_t REG_CONTRAST        = 0x81;
static constexpr uint8_t REG_ENTIRE_ON       = 0xa4;
static constexpr uint8_t REG_NORM_INV        = 0xa6;
static constexpr uint8_t REG_DISP            = 0xae;
static constexpr uint8_t REG_MEM_ADDR        = 0x20;
static constexpr uint8_t REG_COL_ADDR        = 0x21;
static constexpr uint8_t REG_PAGE_ADDR       = 0x22;
static constexpr uint8_t REG_DISP_START_LINE = 0x40;
static constexpr uint8_t REG_SEG_REMAP       = 0xa0;
static constexpr uint8_t REG_COM_OUT_DIR     = 0xc0;
static constexpr uint8_t REG_DISP_OFFSET     = 0xd3;
static constexpr uint8_t REG_COM_PIN_CFG     = 0xda;
static constexpr uint8_t REG_DISP_CLK_DIV    = 0xd5;
static constexpr uint8_t REG_PRECHARGE       = 0xd9;
static constexpr uint8_t REG_VCOM_DESEL      = 0xdb;
static constexpr uint8_t REG_CHARGE_PUMP     = 0x8d;

static constexpr uint8_t COMMAND_TRANSFER = 0x00;
static constexpr uint8_t DATA_TRANSFER    = 0x40;

static constexpr uint8_t SSD1306_I2C_ADDRESS = 0x78;

static constexpr bool upside_down = true;  // Rotate by 180 degrees.
static constexpr bool external_vcc = false;

SSD1306Display::SSD1306Display() {
  I2CMaster::Init();
  Reset();
}

void SSD1306Display::Reset() {
  SetOn(false);

  // Init stuff.
  const uint8_t h = 64;
  static const uint8_t PROGMEM init_sequence[] = {
#ifndef DISP_SH1106
    REG_MEM_ADDR, 0x00,
#endif
    REG_DISP_START_LINE,
    REG_SEG_REMAP | (upside_down ? 0x01 : 0x00),
    REG_COM_OUT_DIR | (upside_down ? 0x08 : 0x00),
    REG_DISP_OFFSET, 0x00,
    REG_COM_PIN_CFG, h == 32 ? 0x02 : 0x12,
    REG_DISP_CLK_DIV, 0x80,
    REG_PRECHARGE, external_vcc ? 0x22 : 0xf1,
    REG_VCOM_DESEL, 0x30,    // 0.83*Vcc
    REG_CONTRAST, 0xff,      // maximum
    REG_ENTIRE_ON,           // output follows RAM contents
    REG_NORM_INV,            // not inverted
    REG_CHARGE_PUMP, external_vcc ? 0x10 : 0x14,
  };
  I2CMaster::StartTransmission(SSD1306_I2C_ADDRESS);
  I2CMaster::Write(COMMAND_TRANSFER);
  for (uint8_t i = 0; i < sizeof(init_sequence); ++i) {
    I2CMaster::Write(pgm_read_byte(&init_sequence[i]));
  }
  I2CMaster::FinishTransmission();

  ClearScreen();
  SetOn(true);
}

void SSD1306Display::SetOn(bool on) {
  I2CMaster::StartTransmission(SSD1306_I2C_ADDRESS);
  I2CMaster::Write(COMMAND_TRANSFER);
  I2CMaster::Write(REG_DISP | on);
  I2CMaster::FinishTransmission();
}

void SSD1306Display::ClearScreen() {
#ifdef DISP_SH1106
  for (uint8_t y = 0; y < 8; ++y) {
    I2CMaster::StartTransmission(SSD1306_I2C_ADDRESS);
    I2CMaster::Write(COMMAND_TRANSFER);
    I2CMaster::Write(0xB0 | y);  // row address
    I2CMaster::Write(0x00 | 2);  // col: 00
    I2CMaster::Write(0x10 | 0);
    I2CMaster::FinishTransmission();

    I2CMaster::StartTransmission(SSD1306_I2C_ADDRESS);
    I2CMaster::Write(DATA_TRANSFER);
    for (uint8_t i = 0; i < 128; ++i)
      I2CMaster::Write(0x00);
    I2CMaster::FinishTransmission();
  }
#else
  const uint8_t cmd[] = {
    REG_COL_ADDR, 0, 127,
    REG_PAGE_ADDR, 0, 0xff,
  };

  I2CMaster::StartTransmission(SSD1306_I2C_ADDRESS);
  I2CMaster::Write(COMMAND_TRANSFER);
  for (uint8_t i = 0; i < sizeof(cmd); ++i)
    I2CMaster::Write(cmd[i]);
  I2CMaster::FinishTransmission();

  I2CMaster::StartTransmission(SSD1306_I2C_ADDRESS);
  I2CMaster::Write(DATA_TRANSFER);
  for (uint16_t i = 0; i < 128 * 8; ++i)
    I2CMaster::Write(0x00);
  I2CMaster::FinishTransmission();
#endif
}

static void StartStripeTx(uint8_t stripe, uint8_t width,
                          uint8_t x_pos, uint8_t y_page) {
  I2CMaster::StartTransmission(SSD1306_I2C_ADDRESS);
  I2CMaster::Write(COMMAND_TRANSFER);

#ifdef DISP_SH1106
  (void)width;
  const uint8_t start_pos = x_pos + 2;
  I2CMaster::Write(0xB0 | (y_page + stripe));  // row address
  I2CMaster::Write(0x00 | (start_pos & 0x0f));
  I2CMaster::Write(0x10 | (start_pos >> 4));
#else
  const uint8_t cmd[] = {
    REG_COL_ADDR, x_pos, (uint8_t)(x_pos + width),
    REG_PAGE_ADDR, (uint8_t)(y_page + stripe), (uint8_t)(y_page + stripe),
  };
  for (uint8_t i = 0; i < sizeof(cmd); ++i)
    I2CMaster::Write(cmd[i]);
#endif
  I2CMaster::FinishTransmission();

  I2CMaster::StartTransmission(SSD1306_I2C_ADDRESS);
  I2CMaster::Write(DATA_TRANSFER);
}

uint8_t SSD1306Display::Print(const FontData &font,
                              uint8_t xpos, const uint8_t ypos,
                              const char *utf8_text) {
  while (*utf8_text) {
    const uint16_t cp = utf8_next_codepoint(utf8_text);
    xpos += BDFONT_EMIT_GLYPH(
      &font, cp, true,
      { StartStripeTx(stripe, glyph_width, xpos, ypos/8); },
      { I2CMaster::Write(b); },
      { I2CMaster::FinishTransmission(); });
  }
  return xpos;
}

void SSD1306Display::FillStripeRange(uint8_t x_from, uint8_t x_to, uint8_t ypos,
                                     uint8_t fill_mask) {
  uint8_t page = ypos / 8;
  I2CMaster::StartTransmission(SSD1306_I2C_ADDRESS);
  I2CMaster::Write(COMMAND_TRANSFER);

#ifdef DISP_SH1106
  const uint8_t start_pos = x_from + 2;
  I2CMaster::Write(COMMAND_TRANSFER);
  I2CMaster::Write(0xB0 | page);  // row address
  I2CMaster::Write(0x00 | (start_pos & 0x0f));
  I2CMaster::Write(0x10 | (start_pos >> 4));
#else
  const uint8_t cmd[] = {
    REG_COL_ADDR, x_from, uint8_t(x_to-1),
    REG_PAGE_ADDR, page, page,
  };

  for (uint8_t i = 0; i < sizeof(cmd); ++i)
    I2CMaster::Write(cmd[i]);
#endif
  I2CMaster::FinishTransmission();

  I2CMaster::StartTransmission(SSD1306_I2C_ADDRESS);
  I2CMaster::Write(DATA_TRANSFER);
  for (uint8_t x = x_from; x < x_to; ++x)
    I2CMaster::Write(fill_mask);
  I2CMaster::FinishTransmission();
}

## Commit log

2019-02-23 Basic support for ssd1306 display with compiled-in fonts.
    o Provide a i2c master that works with ATTiny devices.
    o initialize SSD1306 display and allow to write blocks from
    PROGMEM. There is not enough space for a full frame-buffer
    in the ATTiny.
    o some basic generated compiled-in font in PROGMEM; generated
    from some BDF font.
2019-02-24 Read sag from digital gauge and output radius. First version.
    o Dial gauge uses a very simple serial clock/data protocol transmitting
    24 bits. First 20 bits are the value followed by a sign bit. Last
    bit is a non-metric flag.
    o Reading that and also doing some simple 'gauge is off' detection
    which kicks in when the clock stops transmitting (data is sent
    about 10 times/second)
    o Simple number formatting function to output digits.
    o Do sag calculation using float numbers. Not too bad in terms of
    code memory use and saves the headache of doing fixed point with
    vastly different number magnitudes.
    o Simple first UI that auto-switches between metric/imperial
    [main.cc]
2019-02-24 Update missing glyphs for updated UI. Add sleep mode on indicator off.
    o Update needed characters in fonts for all necessary elements of the UI.
    o When we detect the dial indicator stop clocking data (i.e. it is
    switched off), go to sleep. We still draw about 10μA, but that is
    mostly due to the OLED display. Disconnecting the OLED from GND
    makes current consumption drop to 0.8μA. Maybe add another transistor
    to disconnect OLED ?
    [main.cc]
2019-02-24 Be more conservative waiting for display power on.
    Waiting 100ms does not seem to work well for a slow ramping up
    power source. Make that 500ms.
    Also provide a Reset() function to reset display after sleep.
    [main.cc, ssd1306-display.cc]
2019-02-25 Rename WriteString() to Print() and display to disp to avoid some line-wrappings.
    Purely cosmetic, make code more readable by allowing more lines that
    print to the display fit in one 80 column line.
    [main.cc, ssd1306-display.cc]
2019-02-26 Round values. Make things const where possible. Fix indentation.
    [main.cc]
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2019-02-26 Make places that use fonts a little bit more readable.
    Instead of mouthful
    &progmem_font_smalltext.meta
    we use shortcut
    font_smaltext
    [main.cc]
2019-03-01 Starting a frame to hold the indicator.
    [frame.scad]
2019-03-01 Add a screw-on battery lid.
    [frame.scad]
2019-03-01 Add embedded nuts in print.
    [frame.scad]
2019-03-01 Fix typo in indicator brand.
    [main.cc]
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2019-03-03 Add laser-cut pattern for the leg-holding acrylic base.
    [frame.scad]
2019-03-03 Get rid of the display base. We let the bottom transparent.
    [frame.scad]
2019-03-03 Make battery polarity punches a little more visible.
    [frame.scad]
2019-03-03 Add schematic.
    [spherometer-display.sch]
2019-03-08 Make a 'wiggly' battery back. Looks nicer, but also harder to print.
    [frame.scad]
2019-03-09 Add nut-channels everywhere, so that they can be put in after the print.
    Also: add README and Makefile in frame/ directory.
    [frame.scad]
2019-03-10 Add a battery pictogram in the battery box.
    [frame.scad]
2019-03-10 Make front part not a full width cut, just an insert.
    This way, all case cut lines are entirely inside (except the
    battery case of course).
    [frame.scad]
2019-03-10 Add git-hash print to hidden part of 3D print (for easier later re-print).
    To be able to re-print a part with exactly the given version, add a
    git-hash number and date of the *.scad file in the final output model.
    [frame.scad]
2019-03-10 Add center mount hole to the base-plate. Update images.
    [frame.scad]
2019-03-11 Make sure to poke hole all the way through the base-plate.
    [frame.scad]
2019-03-11 Add a champfer on the top right/left edges of the Battery box.
    Also add a couple of TODOs. Remove the sideways channel for the cable,
    it should go down the back for easier routing.
    [frame.scad]
2019-03-12 Cable management: run indicator data lines on the back.
    [frame.scad]
2019-03-13 Move git-hash from bottom to inside; simplify top clearance.
    The bottom should be as flat as possible for mounting, and we only
    need the git-hash when re-printing something, so inside is perfectly
    good.
    [frame.scad]
2019-03-13 Battery box: align center column to be flush with rim of lid.
    [frame.scad]
2019-03-13 Add groove for 1.5V cable.
    [frame.scad]
2019-03-13 Make top cut-out a bit more 'organic' with a cos()-swing.
    [frame.scad]
2019-03-15 First hacky way to add display holder..
    [frame.scad]
2019-03-16 Smallish cleanup: rename and reorganize things in scad file.
    [frame.scad]
2019-03-16 Fix todo: use display_high parameter properly.
    Also: add secondary front-edge champfer.
    [frame.scad]
2019-03-16 switch off wiggle-back by default (hard to print)
    [frame.scad]
2019-03-17 Wider data channel on back; display: make nut not poke through.
    [frame.scad]
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2019-03-30 Swap clk/data in new board. Do pull-up inside.
    [main.cc]
2019-03-30 Shorten splash-screen to fit with wider fonts.
    [main.cc]
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2019-03-31 back bottom mounting hole: put nut in from top not battery case.
    [frame.scad]
2019-04-05 Widen battery wire hole. Fix indentation.
    [frame.scad]
2019-04-05 Reset accidentally changed parameter.
    [frame.scad]
2019-04-05 Make mounting hole through squeeze-block optionsl.
    [frame.scad]
2019-04-06 Make cable-channels more configurable.
    o Bottom clearance.
    o distance from center.
    o width.
    [frame.scad]
2019-04-08 Adjust display box to fit current larger display.
    [frame.scad]
2019-04-21 Adapt to Kicad 5.1 symbols.
    [spherometer-display.sch]
2019-04-21 Fix relative include to generating stl files.
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2019-04-28 Prepare to be usable with dial indicators that already provide OpenCollector output.
    Add a solder-jumper that allows to directly wire the indicator directly to Attiny.
    [spherometer-display.sch]
2019-04-28 Make board. First placement of components, no routing yet.
    Use EVPAV switch as UI button, which is a neat edge tactile switch.
    [spherometer-display.kicad_pcb]
2019-04-28 Route board; add Makefile to create fab files.
    [spherometer-display.kicad_pcb, spherometer-display.sch]
2019-04-28 Update renderings.
    [spherometer-display.kicad_pcb]
2019-04-28 Make bounding box around programming header more compact.
    [spherometer-display.kicad_pcb]
2019-04-28 Swap pin sequence of indicator connector.
    With a flat cable from the autolet indicator, the GND pin is towards
    the center.
    [spherometer-display.kicad_pcb, spherometer-display.sch]
2019-04-28 Re-add OSHW symbol (it got lost as it was not locked).
    [spherometer-display.kicad_pcb]
2019-05-07 Fix: Attiny85 is the huge 5.3mm SOIC-8 footprint.
    [spherometer-display.kicad_pcb, spherometer-display.sch]
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2019-05-11 New tactile button; slot-access cables; cutouts for components below.
    o The old tactile button was too small and flimsy and disintegrated
    quickly. Use a new one.
    o Cables are not connected anymore with JST connectors (too big), but
    instead slots are provided to solder them in. Also, some space
    above the board is provided for the cable access to minimize space-loss
    due to discomboulated cable entrance.
    o Provide cutouts for places where on the 1.3" displays typically components
    are to be found.
    o Make the board slightly less high as the row of passives in some displays
    starts a bit further up.
    This is work-in-progress. Cleanup of silk-screen has to be done and
    cut-outs need to be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
    [spherometer-display.kicad_pcb, spherometer-display.sch]
2019-05-11 Some cleanup. Also add cut-outs to clear components on SH1106 display back.
    [spherometer-display.kicad_pcb]
2019-05-11 DFM: Add fillets to inner cut-out
    [spherometer-display.kicad_pcb]
2019-05-11 Put programming header legend also on back of board.
    [spherometer-display.kicad_pcb]
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2019-05-11 Un-hide signal layers.
    [spherometer-display.kicad_pcb]
2019-05-11 OshPark uses 1.73mm mill for inner cut-outs; so use 0.9mm radius for shape.
    [spherometer-display.kicad_pcb]
2019-05-11 Also obey the minimum radius requirements for the cable-cutouts.
    [spherometer-display.kicad_pcb]
2019-05-16 Adapt case to new PCB. This involves an integrated button.
    [frame.scad]
2019-05-16 Remove display side-screws.
    [frame.scad]
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2019-05-17 Add ajdustment knob how close the display-case comes to edge.
    [frame.scad]
2019-05-17 Simplify UI: button cycles through mirror sizes directly, show ƒ/N on main screen.
    o No pages anymore. Use the first two lines to show ƒ/N for selected mirror
    size, and ƒ value calculated from sphere (which is just r/2)
    o sag value had to go. Not really needed as this can be read from the
    display of the indicator directly (this was more important in the early
    days to verify that we read what the indicator says).
    o Big font size had to be reduced by one point or so to exactly fit in
    32 pixels (=4 stripes). Thus two small text-lines at the top and one
    large radius value at the bottom don't interfere.
    o The mirror size is shown on the right top, where the physical button
    is point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
    [main.cc, tiny-i2c-master.cc]
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2019-05-26 Make tactile dome poke out a little more.
    [frame.scad]
2019-05-26 Bring switch closer to the edge.
    [spherometer-display.kicad_pcb]
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2019-06-02 Add ball-feet correction.
    (Not sure yet if the math works out for tool-referenced, need to
    have another look).
    [main.cc]
2019-06-02 Add TODO for ball correction calculation when tool-referenced.
    [main.cc]
2019-06-03 Introduce error propagation to show expected error on focal length.
    o Introduce simple class ErrorFloat that represents a floating point
    number with error margins. Define operations +, * and /
    o Represent spherometer radius as such value with an error margin of
    0.1mm (compile time parameter)
    o Instead of fiddling with raw values in main, have the dial indicator
    reader functions already converter their value to an ErrorFloat, in
    which they also add the brand-specific error.
    o Do full calculation using the ErrorFloat values and operations. This
    type and the operators makes reading the code quite natural.
    o Display the focal length with +/- error using this code.
    This was not kind to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
    [main.cc]
2019-06-03 Fix typo in feet-radius error #define macro.
    [main.cc]
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2022-08-14 Update to current KiCAD
    [spherometer-display.kicad_pcb, spherometer-display.kicad_sch, spherometer-display.sch]
2022-08-14 Fix paths to 3D models.
    [spherometer-display.kicad_pcb]
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

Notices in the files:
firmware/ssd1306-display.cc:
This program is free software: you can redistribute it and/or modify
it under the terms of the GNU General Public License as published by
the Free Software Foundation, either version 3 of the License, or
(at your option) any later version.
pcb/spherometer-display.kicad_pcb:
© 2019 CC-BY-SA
